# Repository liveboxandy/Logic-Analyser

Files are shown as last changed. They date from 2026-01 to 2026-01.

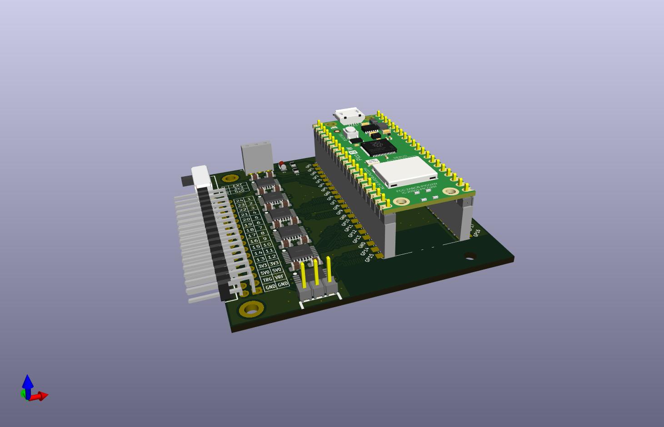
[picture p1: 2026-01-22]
AndyP-Header-design.jpg

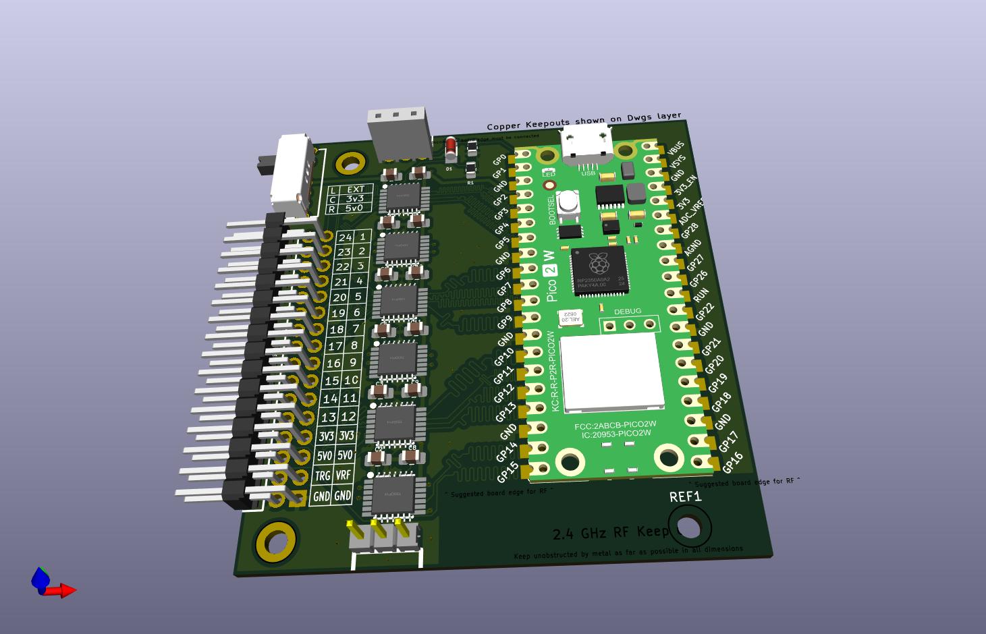
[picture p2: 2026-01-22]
AndyP-design.jpg

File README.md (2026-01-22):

# Logic-Analyser
Cloned and modified from  (https://github.com/gusmanb/logicanalyzer)

Changes from the above are,

1 - Pico can be mounted on headers. Suggest Samtec BBL or SL style.
2 - Uses 0805 rather than 0402 SMT components so I can see and solder them.
3 - Has keepout area for Pico WiFi.
4 - PCB is slightly larger than the orignal.
5 - No ther changes that I can remember

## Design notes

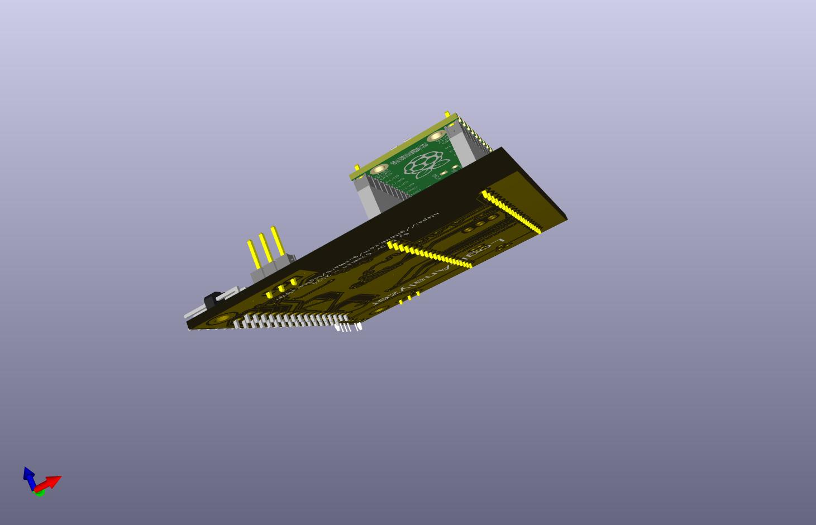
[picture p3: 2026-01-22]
AndyP-Header-design2.jpg

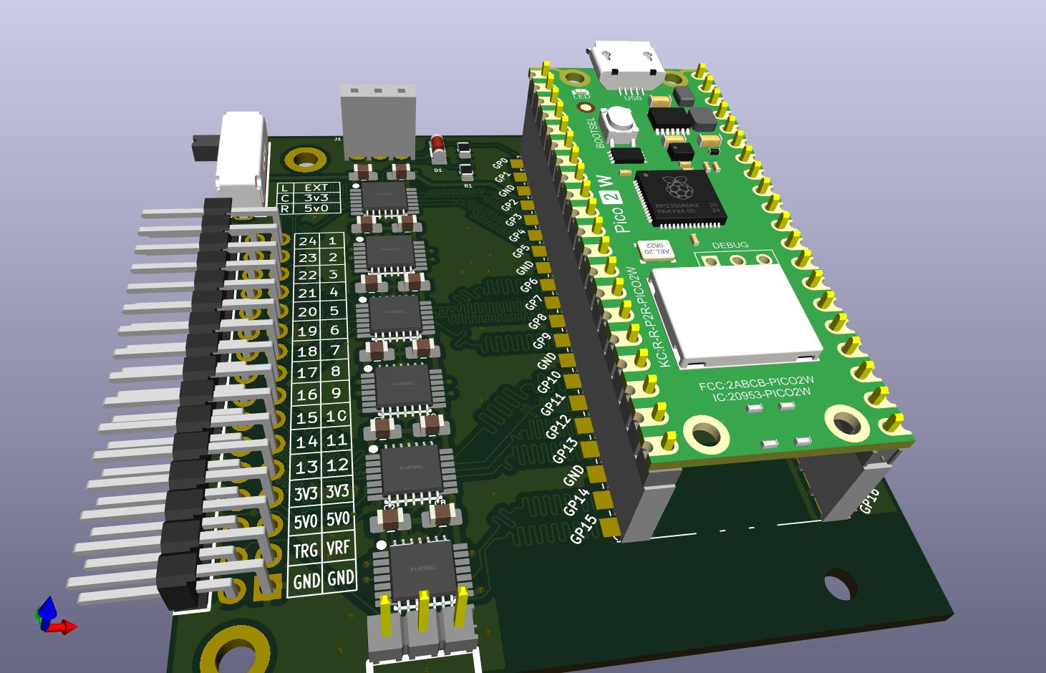
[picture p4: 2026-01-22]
jitx-design.jpg

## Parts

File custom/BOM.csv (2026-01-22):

Comment | Designator | Footprint | LCSC Part Number
75V 500mW 1V@10mA 4ns 200mA LL-34 Switching Diode ROHS | D1 |  | C435829
2.54mm Plugin 3A 3P -40?~+105? Shrouded 1x3P side 8.5mm Square Holes Push-Pull,P=2.54mm Female Headers ROHS | J1 |  | C2897385
3A Shrouded Square Pins 2.54mm 3P 6mm 2.54mm Plugin 1x3P Push-Pull,P=2.54mm Pin Headers ROHS | J3 |  | C2935928
- Raspberry Pi ROHS | U7 |  | C7203002
Lying 1A ???? 24V Black 10000? Plugin Slide Switches ROHS | S1 |  | C2848875
16V 100nF X5R ±20% 0402 Multilayer Ceramic Capacitors MLCC - SMD/SMT ROHS | C9 C4 C11 C3 C8 C1 C12 C6 C7 C2 C10 C5 | 0402 | C344190
1.08V~5.5V 4 200Mbps 1.08V~5.5V TSSOP-14 Translators / Level Shifters ROHS | U2 U5 U4 U3 U6 U1 |  | C2938871
Gold 3A Shrouded Square Pins 2.54mm 32P 6mm -55?~+105? 2.54mm ?? Black Brass 2x16P 2.54mm Push-Pull,P=2.54mm Pin Headers ROHS | J2 |  | C97095
62.5mW Thick Film Resistors 50V ±100ppm/? ±1% 100k? 0402 Chip Resistor - Surface Mount ROHS | R1 | 0402 | C60491
62.5mW Thick Film Resistors 50V ±100ppm/? ±1% 8.2k? 0402 Chip Resistor - Surface Mount ROHS | R2 | 0402 | C409707

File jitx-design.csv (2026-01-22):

Source: | E:\Kicad\LogicAnalyser Mine\jitx-design.kicad_sch
Date: | 2025-12-02T13:05:57+0000
Tool: | Eeschema 9.0.5
Generator: | C:\Program Files\KiCad\7.0\bin\scripting\plugins/bom_csv_grouped_by_value_with_fp.py
Component Count: | 26
Ref | Qnty | Value | Cmp name | Footprint | Description | Vendor | DNP
C1, C2, C3, C4, C5, C6, C7, C8, C9, C10, C11, C12 | 12 | 100n | my_capacitor_11 | Capacitor_SMD:C_0805_2012Metric_Pad1.18x1.45mm_HandSolder
D1 | 1 | LL4148 | C435829 | jitx-design:LL_34_L3_5_W1_5_RD
J1 | 1 | PM254-1-03-W-8.5 | C2897385 | jitx-design:HDR_TH_3P_P2_54_H_F_W10_0_N
J2 | 1 | C97095 | C97095_1 | jitx-design:HDR_TH_32P_P2_54_H_M_R2_C16_S2_54_1
J3 | 1 | DZ254W-11-03-65 | C2935928 | jitx-design:HDR_TH_3P_P2_54_H_M_W10_0
R1 | 1 | 100K | my_resistor_1 | Resistor_SMD:R_0805_2012Metric_Pad1.20x1.40mm_HandSolder
R2 | 1 | 8K2 | my_resistor | Resistor_SMD:R_0805_2012Metric_Pad1.20x1.40mm_HandSolder
S1 | 1 | SK-13D01-G030 | C2848875 | jitx-design:SW_TH_SK_13D01_G030
U1 | 1 | TXU0104PWR | C2938871_5 | jitx-design:TSSOP_14_L5_0_W4_4_P0_65_LS6_4_BL_5
U2 | 1 | TXU0104PWR | C2938871_4 | jitx-design:TSSOP_14_L5_0_W4_4_P0_65_LS6_4_BL_4
U3 | 1 | TXU0104PWR | C2938871 | jitx-design:TSSOP_14_L5_0_W4_4_P0_65_LS6_4_BL
U4 | 1 | TXU0104PWR | C2938871_3 | jitx-design:TSSOP_14_L5_0_W4_4_P0_65_LS6_4_BL_3
U5 | 1 | TXU0104PWR | C2938871_1 | jitx-design:TSSOP_14_L5_0_W4_4_P0_65_LS6_4_BL_1
U6 | 1 | TXU0104PWR | C2938871_2 | jitx-design:TSSOP_14_L5_0_W4_4_P0_65_LS6_4_BL_2
U7 | 1 | PICO 2W | C7203002 | Pico2W:RPi_Pico2W_SMD_TH | - Raspberry Pi ROHS

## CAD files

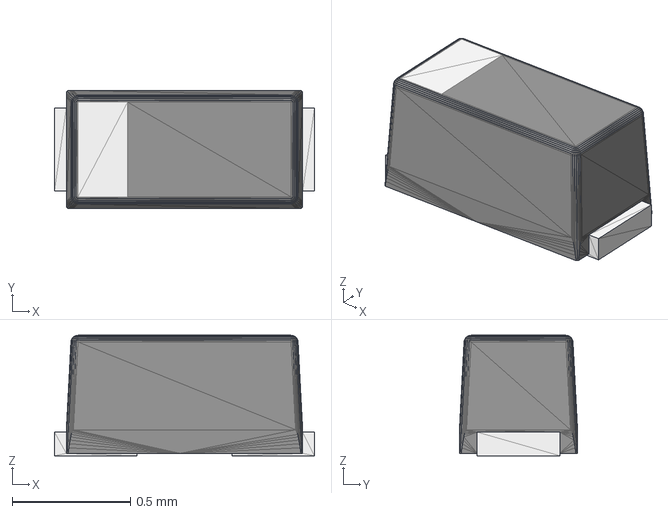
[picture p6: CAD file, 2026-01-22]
3d-models/jitx-64d1493ab789d8dc4b7b3f0a.stp
1.10 x 0.5 x 0.51 mm

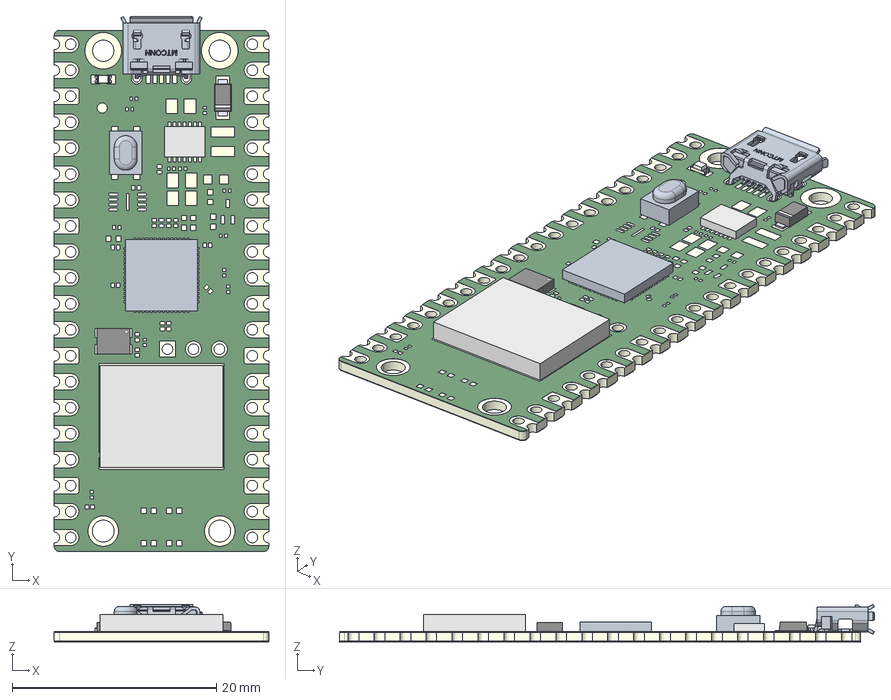
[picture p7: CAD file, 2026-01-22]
3d-models/PicoW.stp
21.0 x 52.4 x 3.66 mm
SOLDERMASK_TOP
Dielectric
SOLDERMASK_BOTTOM
AVAGO_QSM
FCI_10103594-0001LF
RF_SHIELD_PICOW
RPI_RP2040
RT-WDFN-14AL
SOD123FL
TONEPARTS_TP-1221U-K9K5325
XTAL320X250X100

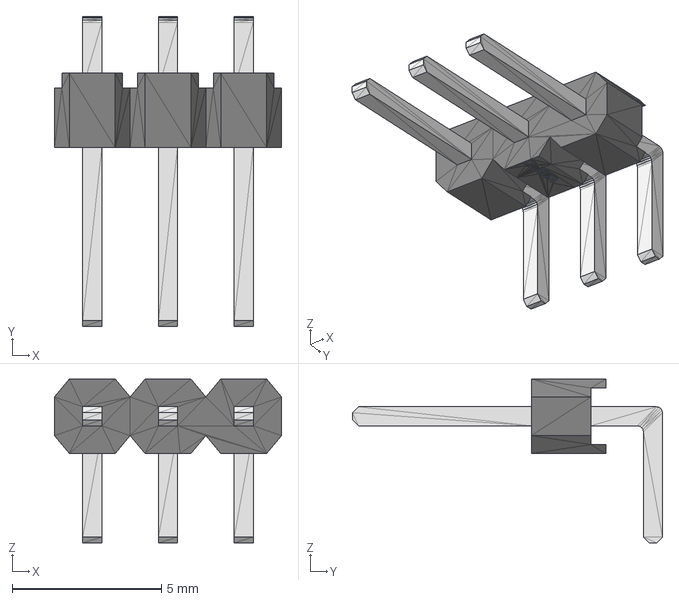
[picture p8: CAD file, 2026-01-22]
3d-models/jitx-64d18ba2b789d8dc4b830bf3.stp
7.62 x 10.4 x 5.50 mm

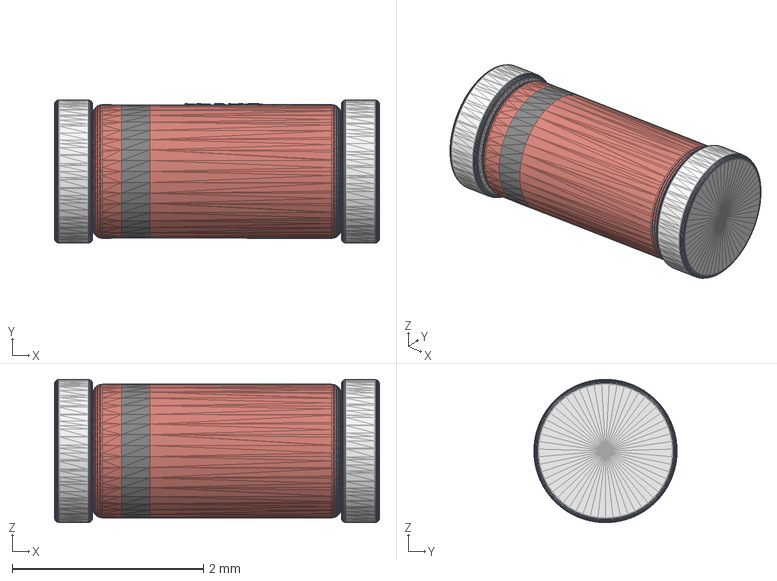
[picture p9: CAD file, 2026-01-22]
3d-models/jitx-64d15923b789d8dc4b7d1a30.stp
3.40 x 1.50 x 1.50 mm

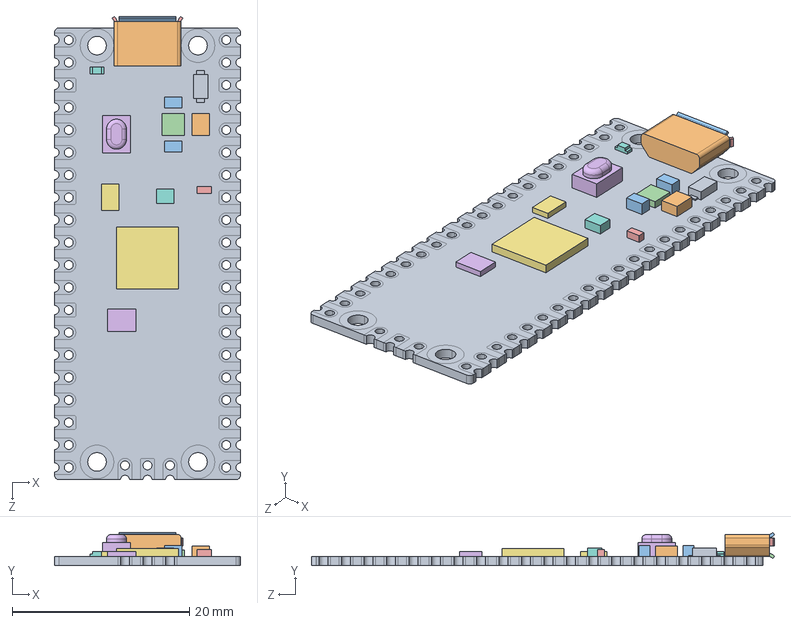
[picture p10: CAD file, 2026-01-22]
3d-models/RP-006426-DD-A-Raspberry Pi Pico 2 3D CAD Model R5 24 07 24.step
21.0 x 3.73 x 52.3 mm
PICO_REF_BOARD
PICO_REF_USB
PICO_REF_SWITCH
PICO_REF_MICROCONTROLLER
PICO_REF_LED
PICO_REF_COMP_1
PICO_REF_COMP_2
PICO_REF_COMP_3 x 2
PICO_REF_COMP_4
PICO_REF_COMP_5
PICO_REF_COMP_6
PICO_REF_COMP_7
PICO_REF_INDUCTOR

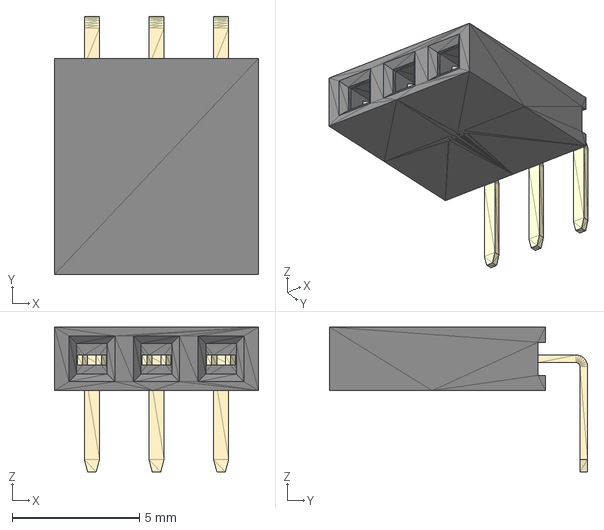
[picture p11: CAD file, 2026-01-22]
3d-models/jitx-64d25c31b789d8dc4b9a488a.stp
8.02 x 10.2 x 5.70 mm

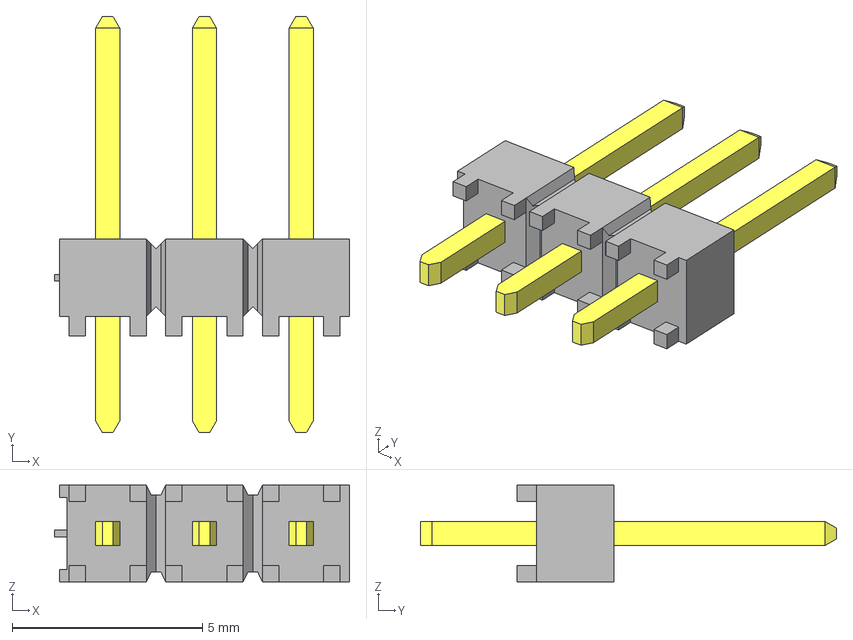
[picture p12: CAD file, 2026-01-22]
3d-models/TSW-103-07-G-S.stp
7.75 x 10.9 x 2.54 mm
TSW-103-07-G-S_body
T-1S6-07-TSW-1-07-3-S

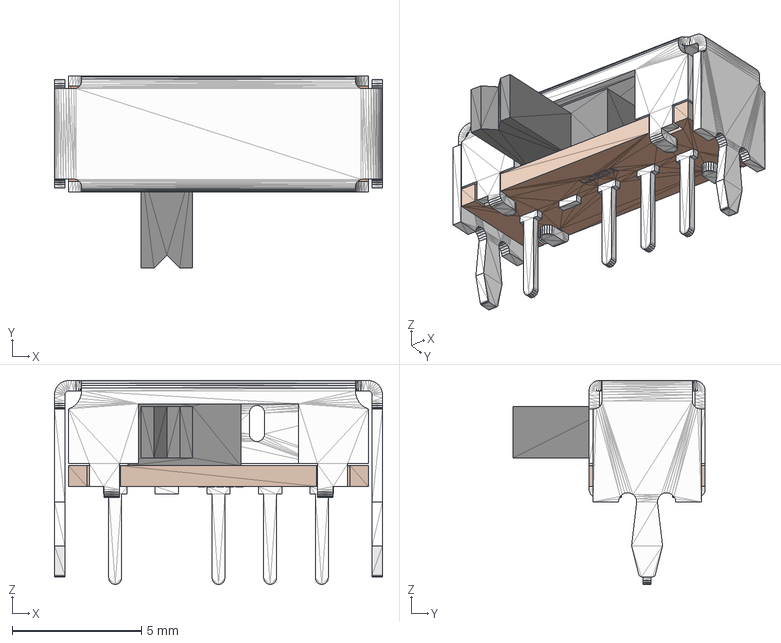
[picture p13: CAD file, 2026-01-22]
3d-models/jitx-64d17702b789d8dc4b808140.stp
12.7 x 7.45 x 7.90 mm

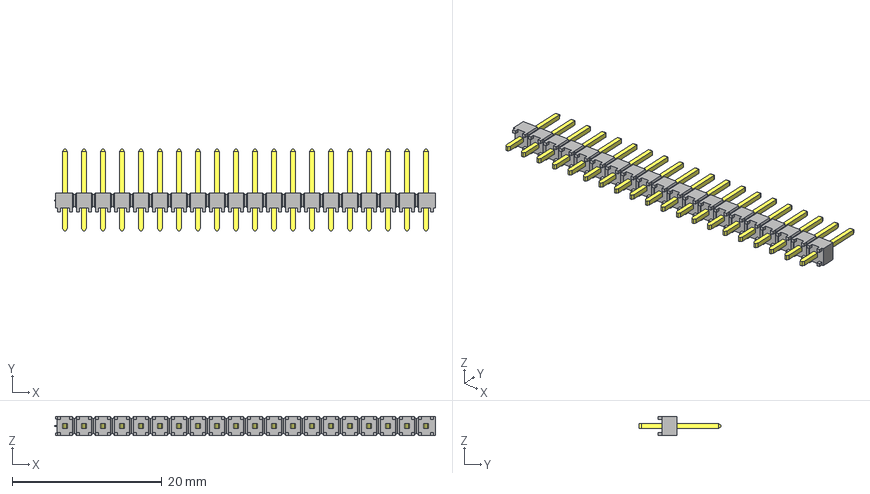
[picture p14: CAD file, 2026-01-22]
3d-models/TSW-120-07-G-S.stp
50.9 x 10.9 x 2.54 mm
TSW-120-07-G-S_body
T-1S6-07-TSW-1-07-20-S

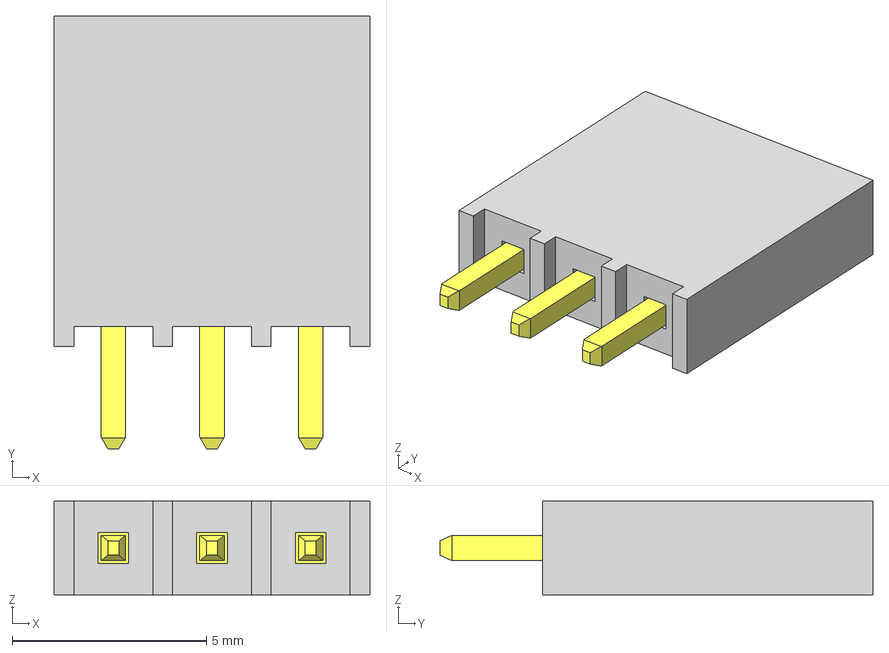
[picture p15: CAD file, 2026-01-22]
3d-models/SSQ-103-01-T-S.stp
8.13 x 11.2 x 2.41 mm
T1SSQ-103-01-T-S
P2SSQ-103-01-T-S

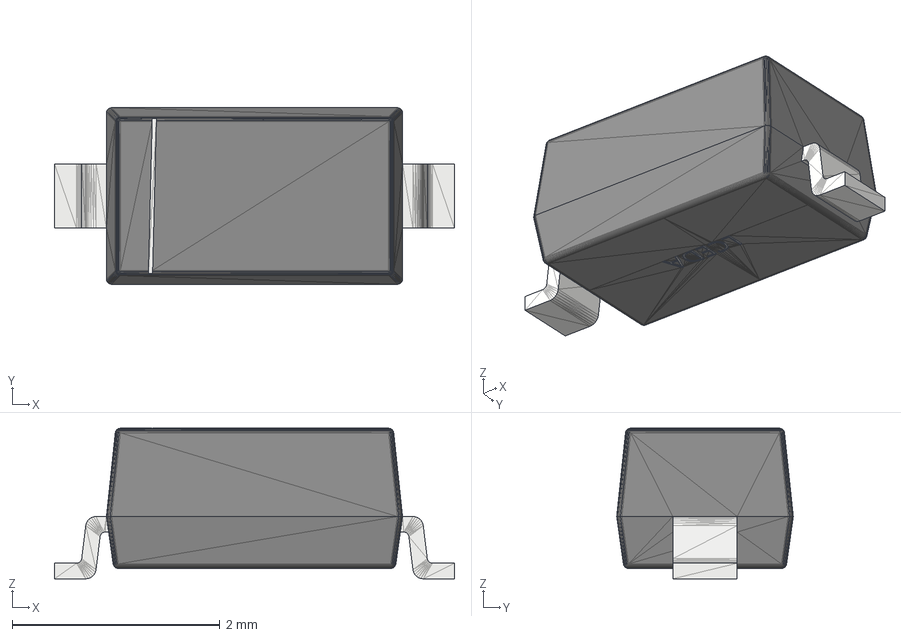
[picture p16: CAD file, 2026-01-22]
3d-models/jitx-64d14728b789d8dc4b7af26c.stp
3.85 x 1.70 x 1.45 mm

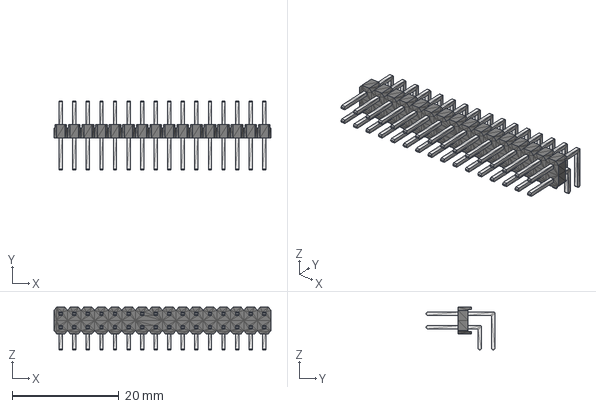
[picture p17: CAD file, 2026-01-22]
3d-models/jitx-64d1fa94b789d8dc4b8f5892.stp
40.6 x 12.9 x 8.00 mm

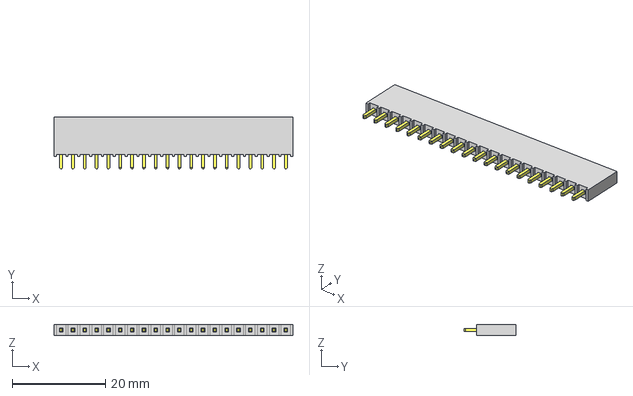
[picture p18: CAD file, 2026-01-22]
3d-models/SSQ-120-01-L-S.stp
51.3 x 11.2 x 2.41 mm
T1SSQ-120-01-L-S
P2SSQ-120-01-L-S

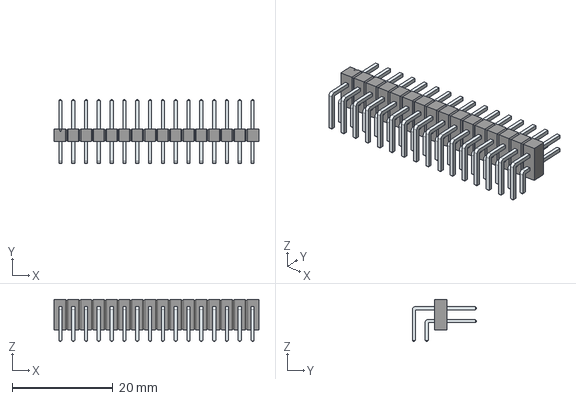
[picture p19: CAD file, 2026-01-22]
3d-models/TSW-116-08-L-D-RA.stp
40.6 x 12.8 x 8.39 mm
LeadsArray x 2

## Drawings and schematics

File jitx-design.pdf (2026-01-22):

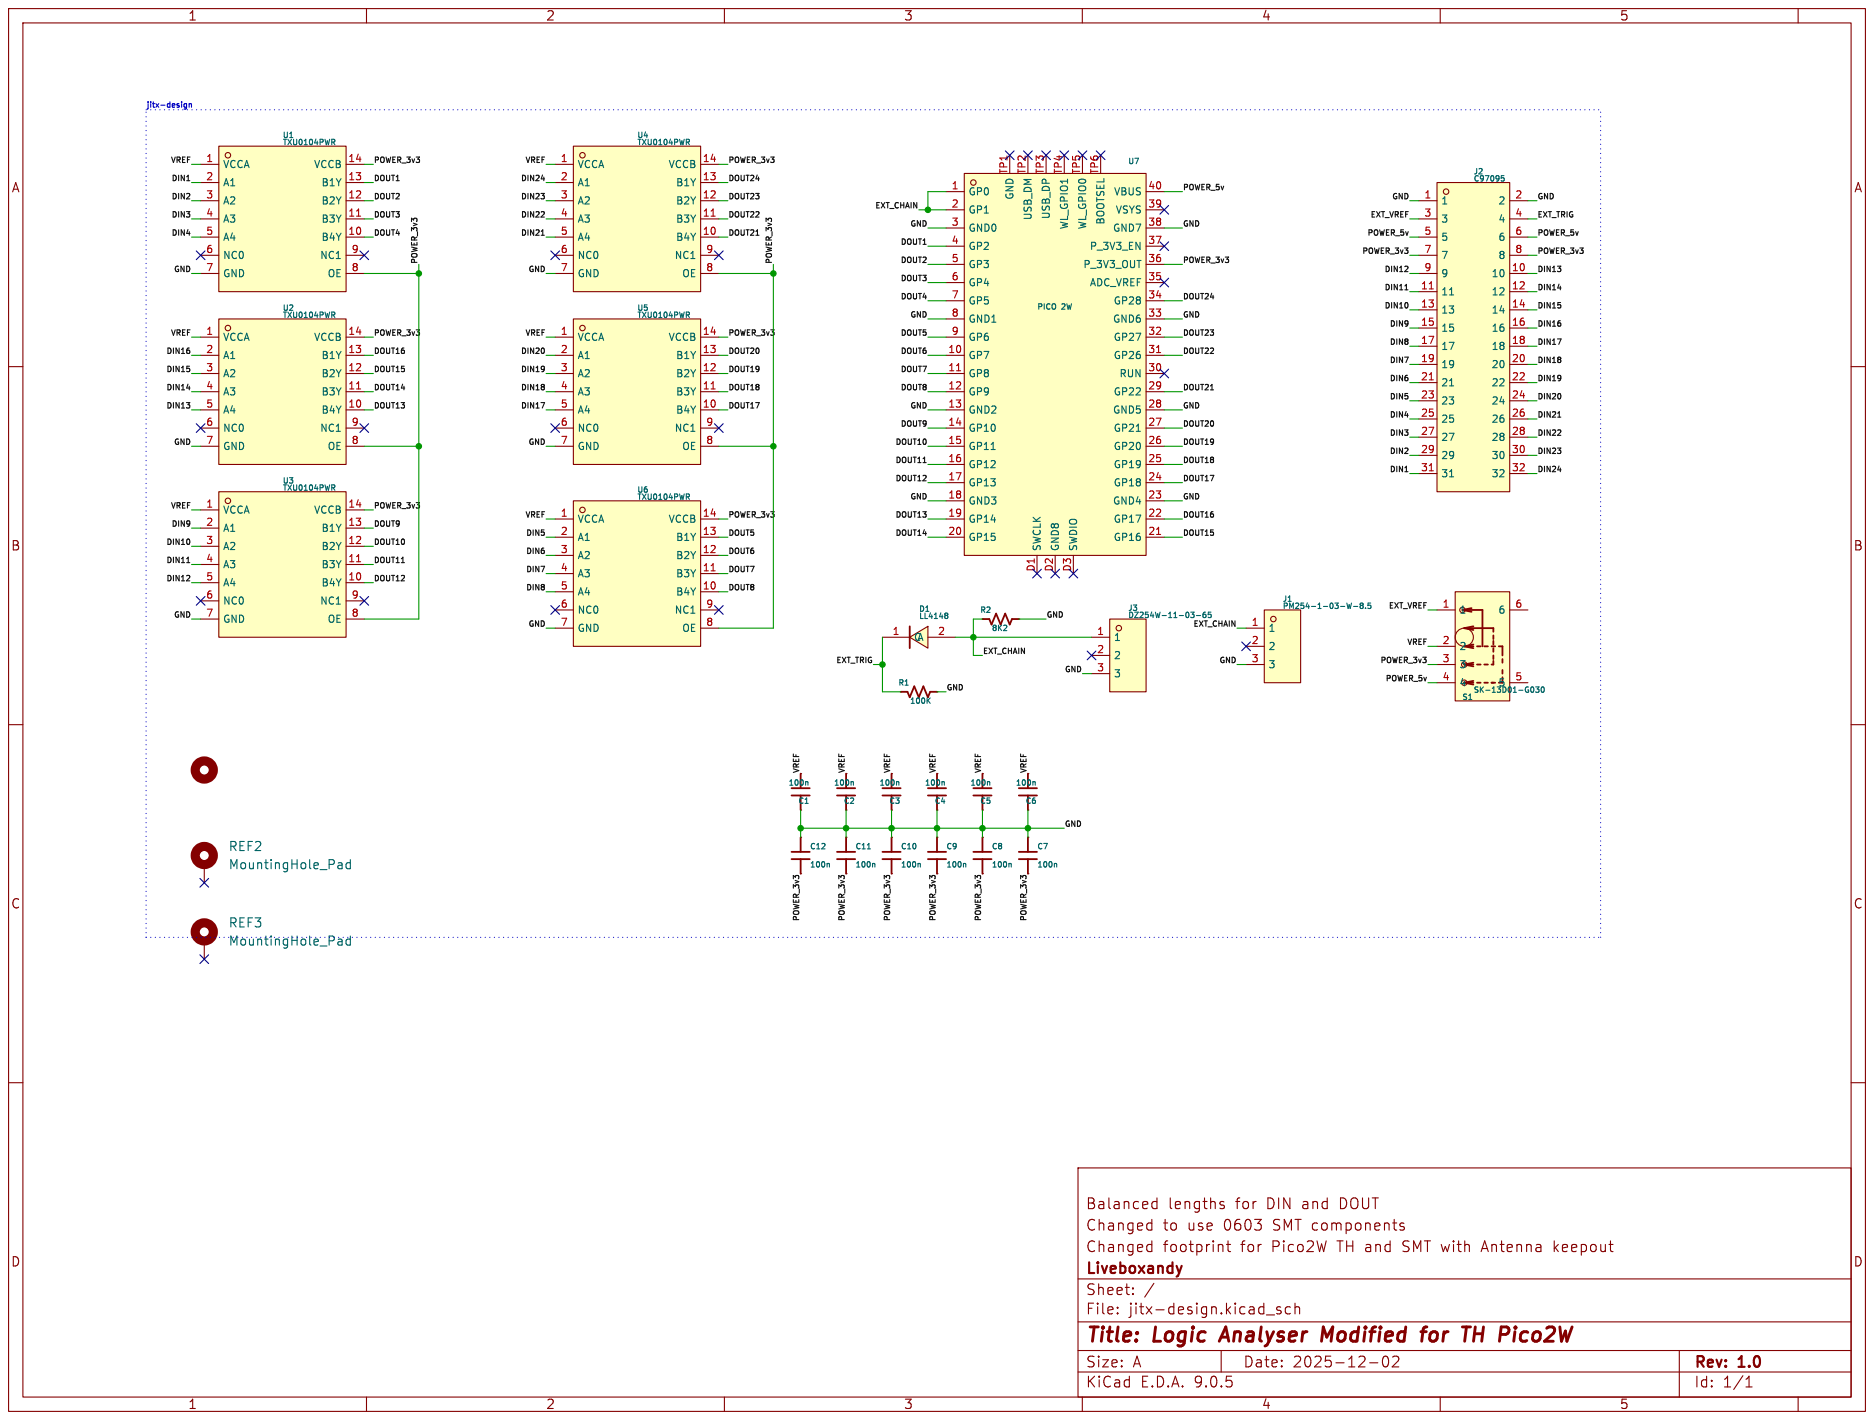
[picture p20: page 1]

File: jitx-design.kicad_sch Sheet: / Liveboxandy

Id: 1/1 Title: Logic Analyser Modified for TH Pico2W

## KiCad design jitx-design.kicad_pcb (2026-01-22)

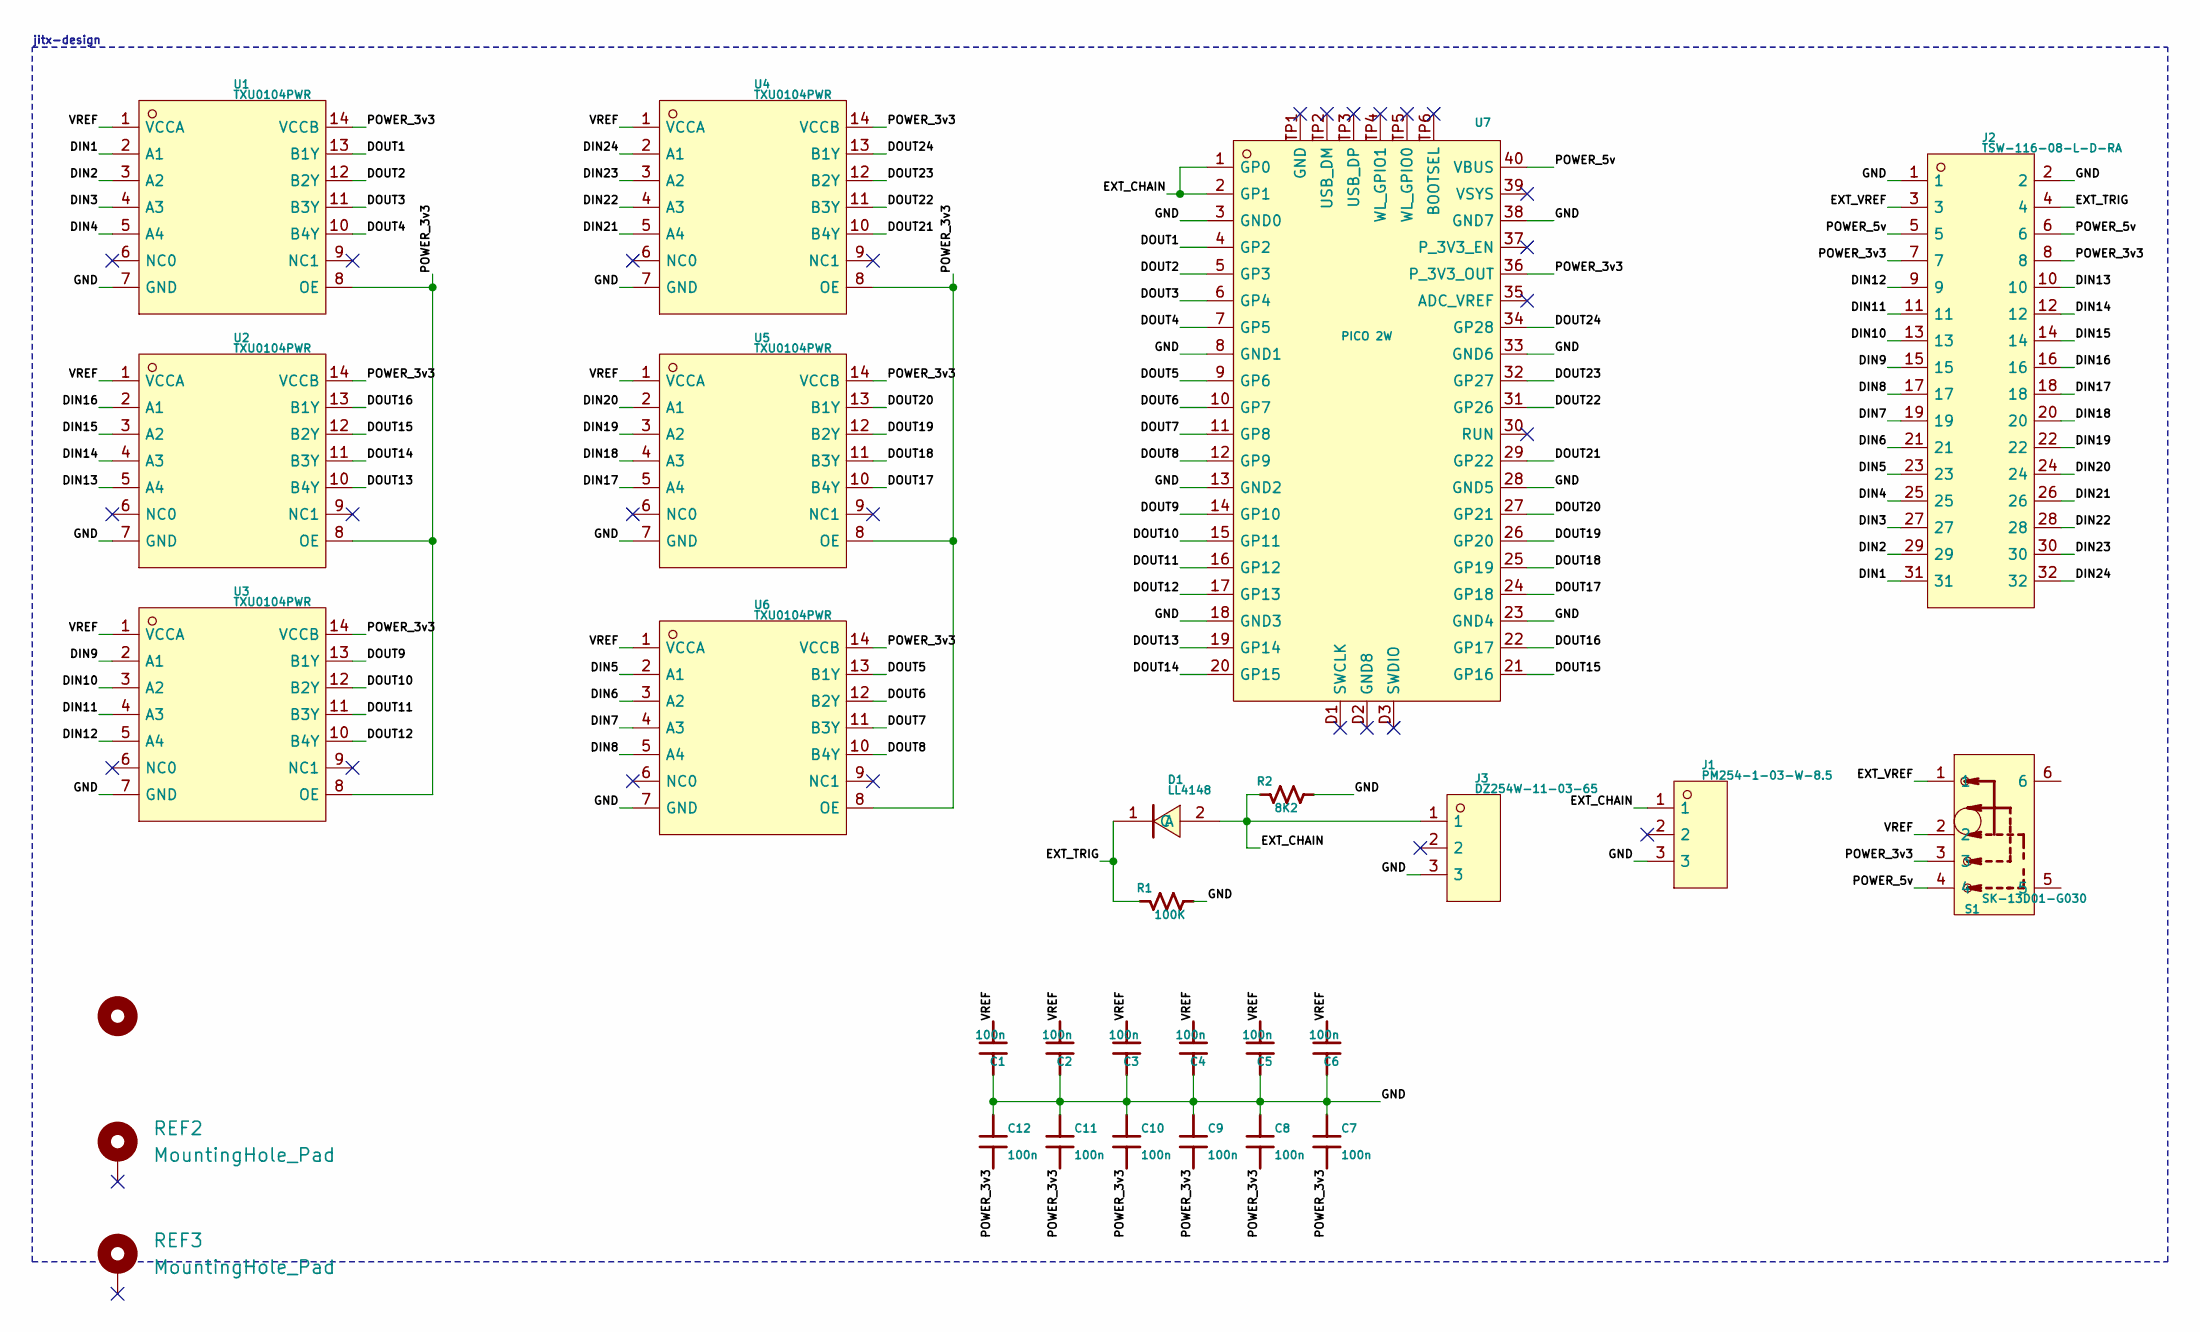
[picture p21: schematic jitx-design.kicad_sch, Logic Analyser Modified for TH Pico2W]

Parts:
C1, C2, C3, C4, C5, C6, C7, C8, C9, C10, C11, C12: 100n; C_0805_2012Metric_Pad1.18x1.45mm_HandSolder; MPN 0402X104M160CT
D1: LL4148; LL_34_L3_5_W1_5_RD; MPN LL4148
J1: PM254-1-03-W-8.5; HDR_TH_3P_P2_54_H_F_W10_0_N; MPN PM254-1-03-W-8.5
J2: TSW-116-08-L-D-RA; HDRRA32W64P254_2X16_4064X254X610P
J3: DZ254W-11-03-65; HDR_TH_3P_P2_54_H_M_W10_0; MPN DZ254W-11-03-65
R1: 100K; R_0805_2012Metric_Pad1.20x1.40mm_HandSolder; MPN CRCW0402100KFKEE
R2: 8K2; R_0805_2012Metric_Pad1.20x1.40mm_HandSolder; MPN CR0402AJW-822GLF
REF1: MountingHole_Pad; MountingHole_2.7mm_M2.5_DIN965
REF2, REF3: MountingHole_Pad; MountingHole_2.7mm_M2.5_DIN965_Pad
S1: SK-13D01-G030; SW_TH_SK_13D01_G030; MPN SK-13D01-G030
U1: TXU0104PWR; TSSOP_14_L5_0_W4_4_P0_65_LS6_4_BL_5; MPN TXU0104PWR
U2: TXU0104PWR; TSSOP_14_L5_0_W4_4_P0_65_LS6_4_BL_4; MPN TXU0104PWR
U3: TXU0104PWR; TSSOP_14_L5_0_W4_4_P0_65_LS6_4_BL; MPN TXU0104PWR
U4: TXU0104PWR; TSSOP_14_L5_0_W4_4_P0_65_LS6_4_BL_3; MPN TXU0104PWR
U5: TXU0104PWR; TSSOP_14_L5_0_W4_4_P0_65_LS6_4_BL_1; MPN TXU0104PWR
U6: TXU0104PWR; TSSOP_14_L5_0_W4_4_P0_65_LS6_4_BL_2; MPN TXU0104PWR
U7: PICO 2W; RPi_Pico2W_SMD_TH; MPN PICO

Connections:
/DIN1: J2.31, U1.2 (A1)
/DIN2: J2.29, U1.3 (A2)
/DIN3: J2.27, U1.4 (A3)
/DIN4: J2.25, U1.5 (A4)
/DIN5: J2.23, U6.2 (A1)
/DIN6: J2.21, U6.3 (A2)
/DIN7: J2.19, U6.4 (A3)
/DIN8: J2.17, U6.5 (A4)
/DIN9: J2.15, U3.2 (A1)
/DIN10: J2.13, U3.3 (A2)
/DIN11: J2.11, U3.4 (A3)
/DIN12: J2.9, U3.5 (A4)
/DIN13: J2.10, U2.5 (A4)
/DIN14: J2.12, U2.4 (A3)
/DIN15: J2.14, U2.3 (A2)
/DIN16: J2.16, U2.2 (A1)
/DIN17: J2.18, U5.5 (A4)
/DIN18: J2.20, U5.4 (A3)
/DIN19: J2.22, U5.3 (A2)
/DIN20: J2.24, U5.2 (A1)
/DIN21: J2.26, U4.5 (A4)
/DIN22: J2.28, U4.4 (A3)
/DIN23: J2.30, U4.3 (A2)
/DIN24: J2.32, U4.2 (A1)
/DOUT1: U1.13 (B1Y), U7.4 (GP2)
/DOUT2: U1.12 (B2Y), U7.5 (GP3)
/DOUT3: U1.11 (B3Y), U7.6 (GP4)
/DOUT4: U1.10 (B4Y), U7.7 (GP5)
/DOUT5: U6.13 (B1Y), U7.9 (GP6)
/DOUT6: U6.12 (B2Y), U7.10 (GP7)
/DOUT7: U6.11 (B3Y), U7.11 (GP8)
/DOUT8: U6.10 (B4Y), U7.12 (GP9)
/DOUT9: U3.13 (B1Y), U7.14 (GP10)
/DOUT10: U3.12 (B2Y), U7.15 (GP11)
/DOUT11: U3.11 (B3Y), U7.16 (GP12)
/DOUT12: U3.10 (B4Y), U7.17 (GP13)
/DOUT13: U2.10 (B4Y), U7.19 (GP14)
/DOUT14: U2.11 (B3Y), U7.20 (GP15)
/DOUT15: U2.12 (B2Y), U7.21 (GP16)
/DOUT16: U2.13 (B1Y), U7.22 (GP17)
/DOUT17: U5.10 (B4Y), U7.24 (GP18)
/DOUT18: U5.11 (B3Y), U7.25 (GP19)
/DOUT19: U5.12 (B2Y), U7.26 (GP20)
/DOUT20: U5.13 (B1Y), U7.27 (GP21)
/DOUT21: U4.10 (B4Y), U7.29 (GP22)
/DOUT22: U4.11 (B3Y), U7.31 (GP26)
/DOUT23: U4.12 (B2Y), U7.32 (GP27)
/DOUT24: U4.13 (B1Y), U7.34 (GP28)
/EXT_CHAIN: D1.2 (A), J1.1, J3.1, R2.1, U7.1 (GP0), U7.2 (GP1)
/EXT_TRIG: D1.1 (C), J2.4, R1.1
/EXT_VREF: J2.3, S1.1
/GND: C1.1, C2.1, C3.1, C4.1, C5.1, C6.1, C7.1, C8.1, C9.1, C10.1, C11.1, C12.1, J1.3, J2.1, J2.2, J3.3, R1.2, R2.2, U1.7 (GND), U2.7 (GND), U3.7 (GND), U4.7 (GND), U5.7 (GND), U6.7 (GND), U7.3 (GND0), U7.8 (GND1), U7.13 (GND2), U7.18 (GND3), U7.23 (GND4), U7.28 (GND5), U7.33 (GND6), U7.38 (GND7)
/POWER_3v3: C7.2, C8.2, C9.2, C10.2, C11.2, C12.2, J2.7, J2.8, S1.3, U1.8 (OE), U1.14 (VCCB), U2.8 (OE), U2.14 (VCCB), U3.8 (OE), U3.14 (VCCB), U4.8 (OE), U4.14 (VCCB), U5.8 (OE), U5.14 (VCCB), U6.8 (OE), U6.14 (VCCB), U7.36 (P_3V3_OUT)
/POWER_5v: J2.5, J2.6, S1.4, U7.40 (VBUS)
/VREF: C1.2, C2.2, C3.2, C4.2, C5.2, C6.2, S1.2, U1.1 (VCCA), U2.1 (VCCA), U3.1 (VCCA), U4.1 (VCCA), U5.1 (VCCA), U6.1 (VCCA)

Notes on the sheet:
jitx-design

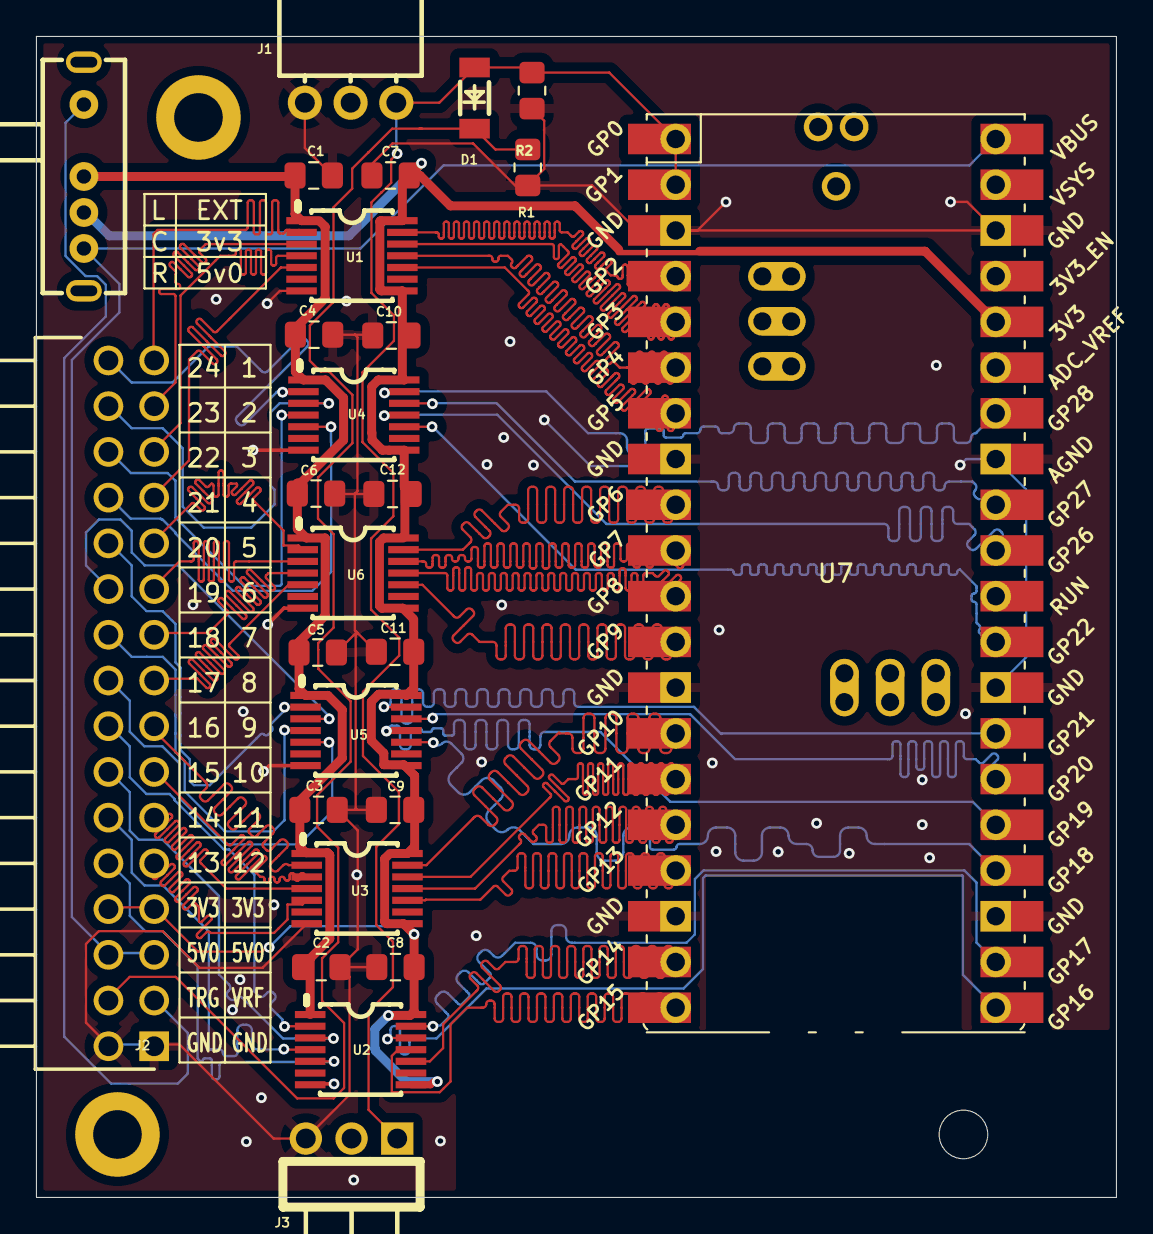
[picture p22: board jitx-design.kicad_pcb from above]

Board: 2 copper layers, 60.0 x 64.5 mm, 29 parts (0 on the bottom side), 55 nets.

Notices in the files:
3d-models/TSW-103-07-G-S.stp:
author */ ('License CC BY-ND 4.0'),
